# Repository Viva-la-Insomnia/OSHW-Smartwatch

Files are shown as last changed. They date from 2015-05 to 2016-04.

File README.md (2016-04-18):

# OSHW-Smartwatch
This is a repo for EFM32-based smartwatch project.
-- Tuomas Tinus, Jimi Järvelin

Contribute by contacting us / sending in a pull request. 
Welcome additions: integration of https://github.com/NordicSemiconductor/ble-sdk-efm32/, USB code. 
Read the README in the Simplicity_project/ on Simplicity IDE setup details

Our code and hardware are GNU GPL v2 / CERN OHL v1.2, licenses are in the repo. 
However, note that external libraries used in this project are distributed under different licenses, e.g. ARM CMSIS is shared under BSD

Features of the project: 
 - EFM32 low-power microcontroller
 - Lithium battery-powered with charge over USB and battery gauging
 - Bluetooth Low-Energy interface
 - Inertial Measurement Unit (Accelerometer, Gyroscope, Magnetometer)
 - Sharp low-power memory display
 - Separate I2C EEPROM memory (up to 1MB in the current iteration)(switching to flash in the final version)
 - Possible password manager functionality with EFM32 hardware encryption

Current state of project: We have assembled a prototype and are debugging the software. Due to high workload the development has been promptly suspended and will resume in early June 2016

We would like to thank Jared Sanson - http://jared.geek.nz/2014/jul/oshw-oled-watch - for inspiration and design ideas.
Kris Winer - https://github.com/kriswiner/MPU-9250/ - for his MPU-9250 code

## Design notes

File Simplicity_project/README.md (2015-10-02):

How to setup Simplicity IDE for this project
1. Edit Anastasia.slsproj to replace #PATH_TO_PROJECT_DIR with location for your OSHW-Smartwatch repo clone
2. Open Simplicity IDE and press File/Import
3. Select Simplicity Studio/MCU Project
4. Browse the tree to the Anastasia.slsproj
5. If not automatically set, choose Kit as None, EFM32GG332F1024 as the part, EFM32 v4.0.0 SDK, and GNU ARM v4.8.3 toolchain
6. Edit the project directory to (your OSHW-Smartwatch repo clone)/OSHW-Smartwatch/Simplicity_project
Done!

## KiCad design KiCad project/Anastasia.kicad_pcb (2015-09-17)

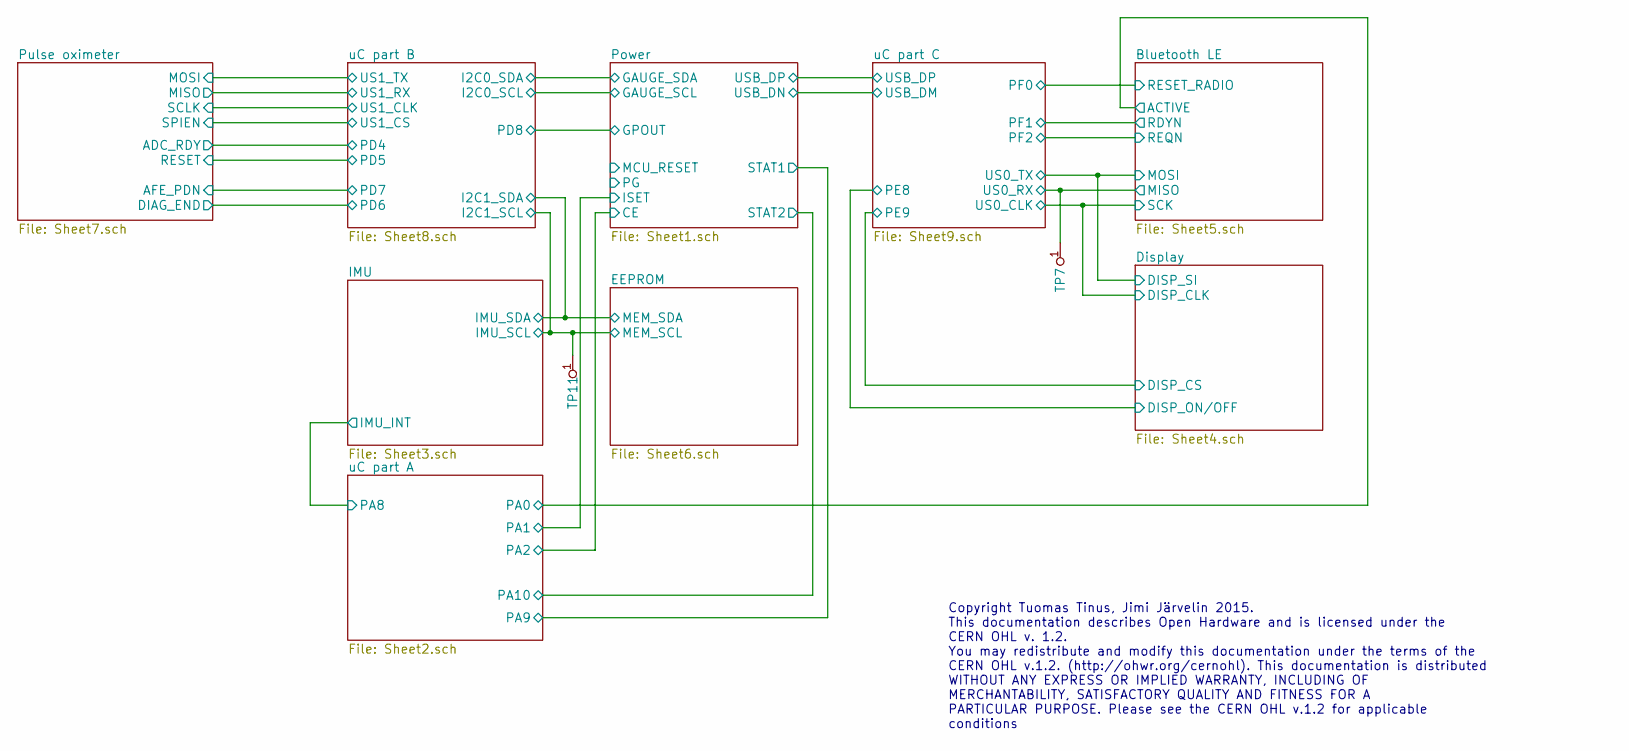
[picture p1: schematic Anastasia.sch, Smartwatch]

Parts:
TP7, TP11: TESTPAD; Test_Point_Round-SMD-Pad

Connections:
/Bluetooth LE/MISO: TP7.1; also elsewhere on the board
/uC part B/I2C1_SCL: TP11.1; also elsewhere on the board

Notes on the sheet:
Copyright Tuomas Tinus, Jimi Järvelin 2015. This documentation describes Open Hardware and is licensed under the CERN OHL v. 1.2. You may redistribute and modify this documentation under the terms of the CERN OHL v.1.2. (http://ohwr.org/cernohl). This documentation is distributed WITHOUT ANY EXPRES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

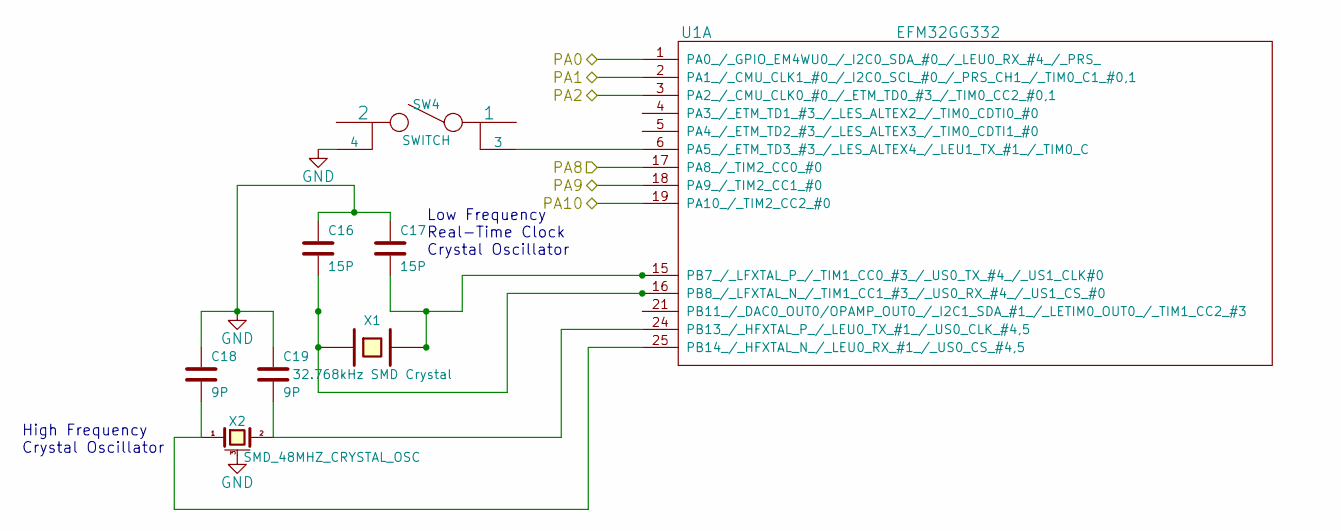
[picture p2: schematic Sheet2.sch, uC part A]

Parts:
C16, C17: 15P; C_0603
C18, C19: 9P; C_0603
SW4: SWITCH; KMS_SMD_SW
U1: EFM32GG332; TQFP-64_10x10mm_Pitch0.5mm
X1: 32.768kHz SMD Crystal; 1.6x1.0CRYSTAL
X2: SMD_48MHZ_CRYSTAL_OSC; 2x1.6

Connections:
/Bluetooth LE/ACTIVE: U1.1 (PA0_/_GPIO_EM4WU0_/_I2C0_SDA_#0_/_LEU0_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); also elsewhere on the board
/IMU/IMU_INT: U1.17 (PA8_/_TIM2_CC0_#0); also elsewhere on the board
/Power/CE: U1.3 (PA2_/_CMU_CLK0_#0_/_ETM_TD0_#3_/_TIM0_C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); also elsewhere on the board
/Power/ISET: U1.2 (PA1_/_CMU_CLK1_#0_/_I2C0_SCL_#0_/_PRS_C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); also elsewhere on the board
/uC part A/PA9: U1.18 (PA9_/_TIM2_CC1_#0); also elsewhere on the board
/uC part A/PA10: U1.19 (PA10_/_TIM2_CC2_#0); also elsewhere on the board
GND: C16.1, C17.1, C18.1, C19.1, SW4.4, X2.3 (case); also elsewhere on the board
unnamed: C16.2, U1.16 (PB8_/_LFXTAL_N_/_TIM1_CC1_#3_/_US0_RX_#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), X1.1
unnamed: C17.2, U1.15 (PB7_/_LFXTAL_P_/_TIM1_CC0_#3_/_US0_TX_#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), X1.2
unnamed: C18.2, U1.25 (PB14_/_HFXTAL_N_/_LEU0_RX_#1_/_US0_CS_#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), X2.1
unnamed: C19.2, U1.24 (PB13_/_HFXTAL_P_/_LEU0_TX_#1_/_US0_CLK_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), X2.2
unnamed: SW4.3, U1.6 (PA5_/_ETM_TD3_#3_/_LES_ALTEX4_/_LEU1_TX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)

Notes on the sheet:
High Frequency Crystal Oscillator
Low Frequency Real-Time Clock Crystal Oscillator

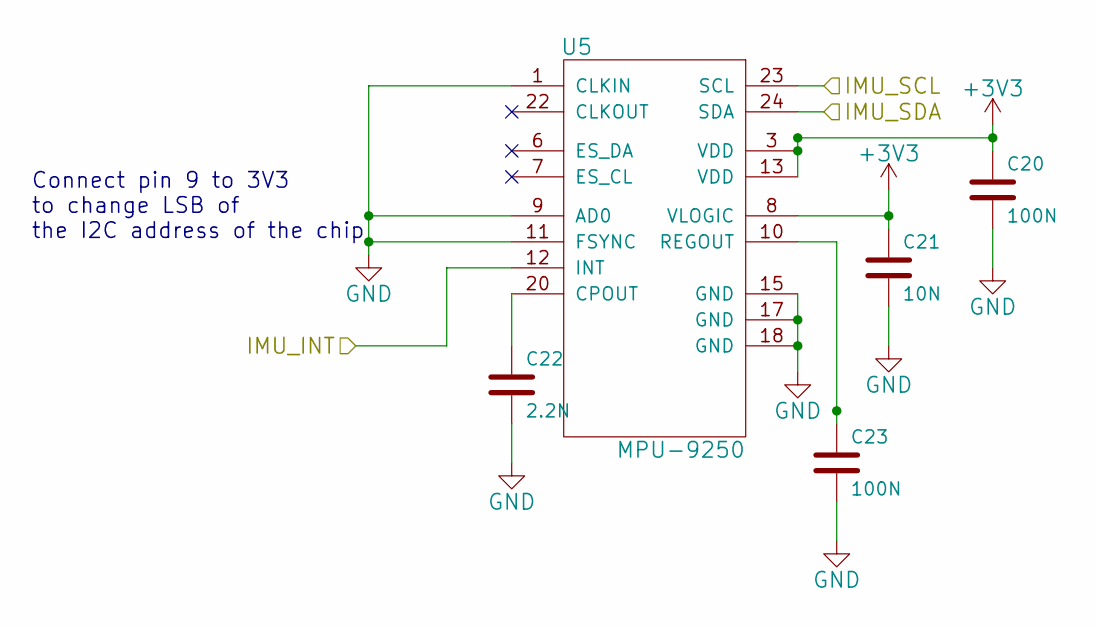
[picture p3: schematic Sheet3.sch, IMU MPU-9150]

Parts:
C20, C23: 100N; C_0603
C21: 10N; C_0603
C22: 2.2N; C_0603
U5: MPU-9250; LGA24

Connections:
+3V3: C20.1, C21.1, U5.3 (VDD), U5.8 (VLOGIC), U5.13 (VDD); also elsewhere on the board
/IMU/IMU_INT: U5.12 (INT); also elsewhere on the board
/uC part B/I2C1_SCL: U5.23 (SCL); also elsewhere on the board
/uC part B/I2C1_SDA: U5.24 (SDA); also elsewhere on the board
GND: C20.2, C21.2, C22.2, C23.2, U5.1 (CLKIN), U5.5 (RESV), U5.9 (AD0), U5.11 (FSYNC), U5.15 (GND), U5.17 (GND), U5.18 (GND); also elsewhere on the board
unnamed: C22.1, U5.20 (CPOUT)
unnamed: C23.1, U5.10 (REGOUT)

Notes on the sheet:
Connect pin 9 to 3V3 to change LSB of the I2C address of the chip

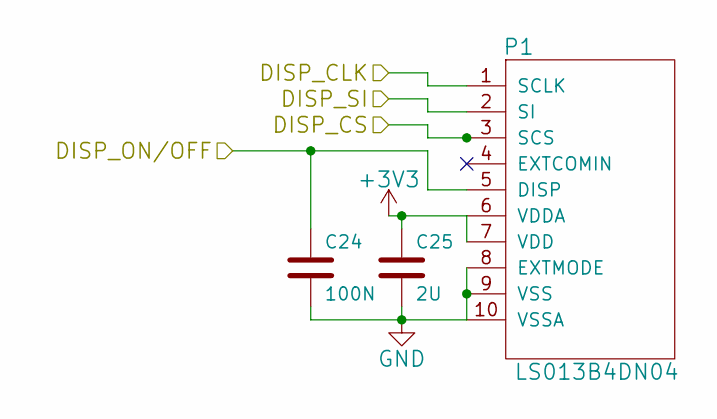
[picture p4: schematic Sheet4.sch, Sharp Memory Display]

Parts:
C24: 100N; C_0603
C25: 2U; C_0603
P1: LS013B4DN04; FPC10

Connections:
+3V3: C25.1, P1.6 (VDDA), P1.7 (VDD); also elsewhere on the board
/Display/DISP_CLK: P1.1 (SCLK); also elsewhere on the board
/Display/DISP_CS: P1.3 (SCS); also elsewhere on the board
/Display/DISP_ON/OFF: C24.1, P1.5 (DISP); also elsewhere on the board
/Display/DISP_SI: P1.2 (SI); also elsewhere on the board
GND: C24.2, C25.2, P1.8 (EXTMODE), P1.9 (VSS), P1.10 (VSSA); also elsewhere on the board

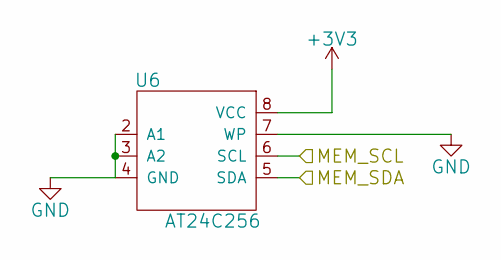
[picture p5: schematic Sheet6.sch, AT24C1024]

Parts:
U6: AT24C256; SOIC-8_3.9x4.9mm_Pitch1.27mm

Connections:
+3V3: U6.8 (VCC); also elsewhere on the board
/uC part B/I2C1_SCL: U6.6 (SCL); also elsewhere on the board
/uC part B/I2C1_SDA: U6.5 (SDA); also elsewhere on the board
GND: U6.2 (A1), U6.3 (A2), U6.4 (GND), U6.7 (WP); also elsewhere on the board

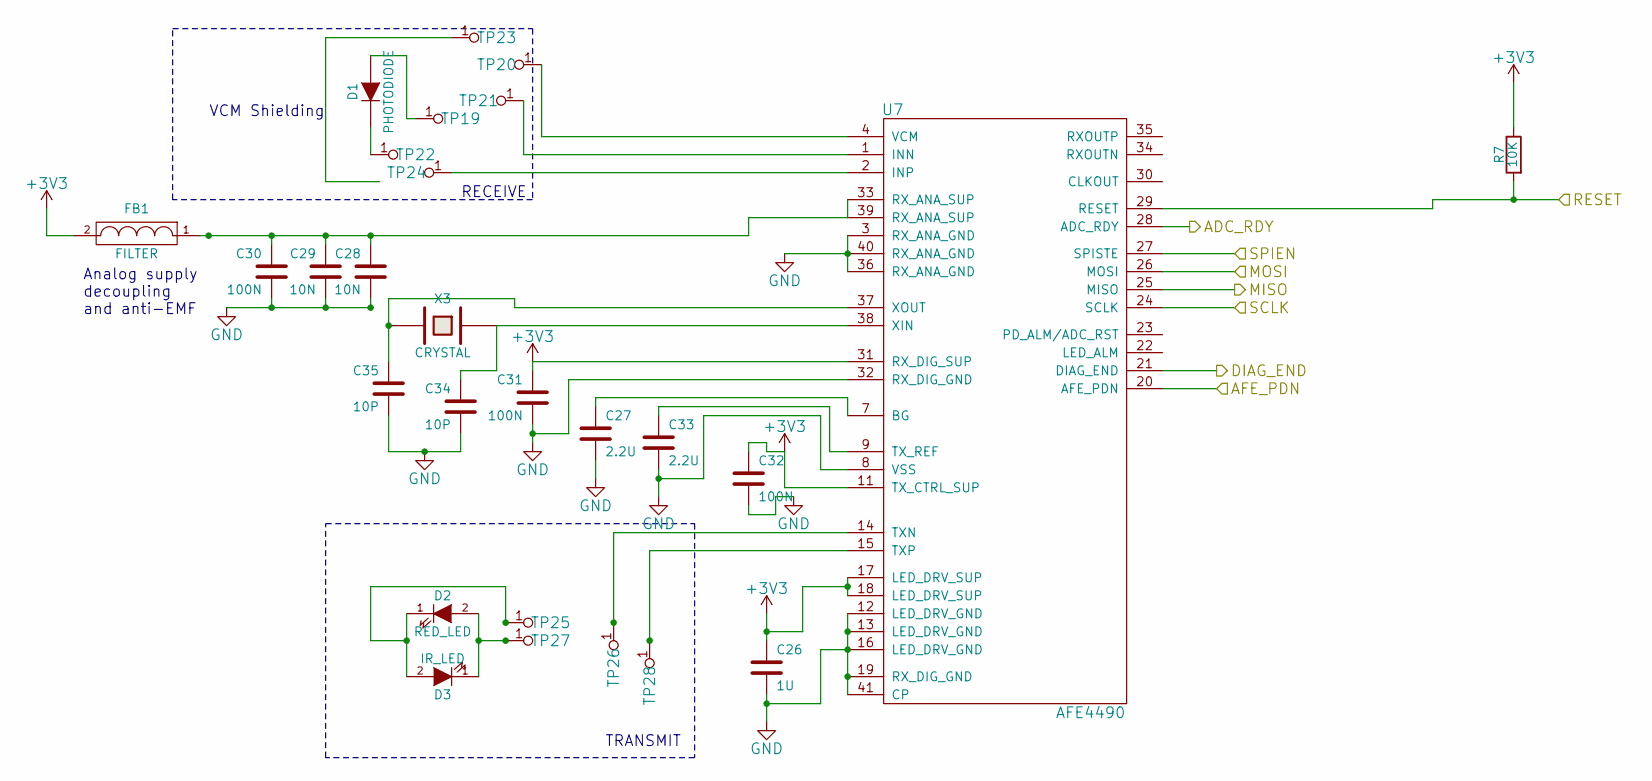
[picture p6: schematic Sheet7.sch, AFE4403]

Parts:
C26: 1U; C_0603
C27, C33: 2.2U; C_0603
C28, C29: 10N; C_0603
C30, C31, C32: 100N; C_0603
C34, C35: 10P; C_0603
D1: PHOTODIODE; BPW34S
D2: RED_LED; R_0603_HandSoldering
D3: IR_LED; 2x1.25mm_LED
FB1: FILTER; C_0603
R7: 10K; R_0603
TP19, TP20, TP21, TP22, TP23, TP24, TP25, TP26, TP27, TP28: TESTPAD; Test_Point_Round-SMD-Pad
U7: AFE4490; QFN40
X3: CRYSTAL; Crystal_Round_Horizontal_3mm

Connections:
+3V3: C26.1, C31.1, C32.1, FB1.2, R7.1, U7.11 (TX_CTRL_SUP), U7.17 (LED_DRV_SUP), U7.18 (LED_DRV_SUP), U7.31 (RX_DIG_SUP); also elsewhere on the board
/Pulse oximeter /ADC_RDY: U7.28 (ADC_RDY); also elsewhere on the board
/Pulse oximeter /AFE_PDN: U7.20 (AFE_PDN); also elsewhere on the board
/Pulse oximeter /DIAG_END: U7.21 (DIAG_END); also elsewhere on the board
/Pulse oximeter /MISO: U7.25 (MISO); also elsewhere on the board
/Pulse oximeter /MOSI: U7.26 (MOSI); also elsewhere on the board
/Pulse oximeter /SCLK: U7.24 (SCLK); also elsewhere on the board
/Pulse oximeter /SPIEN: U7.27 (SPISTE); also elsewhere on the board
/uC part B/PD5: R7.2, U7.29 (RESET); also elsewhere on the board
GND: C26.2, C27.2, C28.2, C29.2, C30.2, C31.2, C32.2, C33.2, C34.2, C35.2, U7.3 (RX_ANA_GND), U7.8 (VSS), U7.12 (LED_DRV_GND), U7.13 (LED_DRV_GND), U7.16 (LED_DRV_GND), U7.19 (RX_DIG_GND), U7.32 (RX_DIG_GND), U7.36 (RX_ANA_GND), U7.40 (RX_ANA_GND), U7.41 (CP); also elsewhere on the board
unnamed: C27.1, U7.7 (BG)
unnamed: C28.1, C29.1, C30.1, FB1.1, U7.33 (RX_ANA_SUP), U7.39 (RX_ANA_SUP)
unnamed: C33.1, U7.9 (TX_REF)
unnamed: C34.1, U7.38 (XIN), X3.1
unnamed: C35.1, U7.37 (XOUT), X3.2
unnamed: D1.1 (A), TP19.1
unnamed: D1.2 (K), TP22.1
unnamed: D2.1 (K), D3.2 (A), TP25.1
unnamed: D2.2 (A), D3.1 (K), TP27.1
unnamed: TP20.1, U7.4 (VCM)
unnamed: TP21.1, U7.1 (INN)
unnamed: TP24.1, U7.2 (INP)
unnamed: TP26.1, U7.14 (TXN)
unnamed: TP28.1, U7.15 (TXP)

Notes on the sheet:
TRANSMIT
RECEIVE
VCM Shielding
Analog supply decoupling and anti-EMF

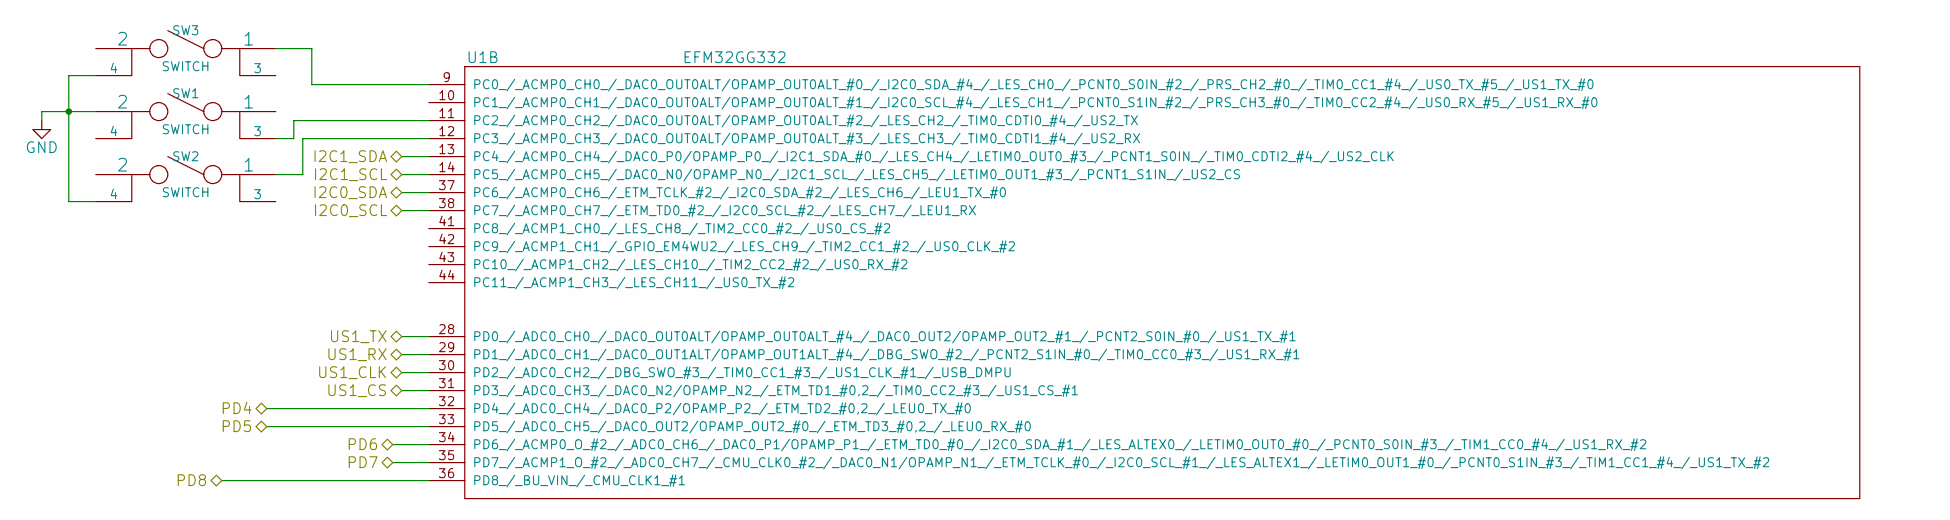
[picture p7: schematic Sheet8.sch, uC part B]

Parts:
SW1, SW2, SW3: SWITCH; KMS_SMD_SW
U1: EFM32GG332; TQFP-64_10x10mm_Pitch0.5mm

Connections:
/Power/GAUGE_SCL: U1.38 (PC7_/_ACMP0_CH7_/_ETM_TD0_#2_/_I2C0_SCL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); also elsewhere on the board
/Power/GAUGE_SDA: U1.37 (PC6_/_ACMP0_CH6_/_ETM_TCLK_#2_/_I2C0_SD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); also elsewhere on the board
/Power/GPOUT: U1.36 (PD8_/_BU_VIN_/_CMU_CLK1_#1); also elsewhere on the board
/Pulse oximeter /ADC_RDY: U1.32 (PD4_/_ADC0_CH4_/_DAC0_P2/OPAMP_P2_/_ETM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); also elsewhere on the board
/Pulse oximeter /AFE_PDN: U1.35 (PD7_/_ACMP1_O_#2_/_ADC0_CH7_/_CMU_CLK0_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); also elsewhere on the board
/Pulse oximeter /DIAG_END: U1.34 (PD6_/_ACMP0_O_#2_/_ADC0_CH6_/_DAC0_P1/O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); also elsewhere on the board
/Pulse oximeter /MISO: U1.29 (PD1_/_ADC0_CH1_/_DAC0_OUT1ALT/OPAMP_OUT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); also elsewhere on the board
/Pulse oximeter /MOSI: U1.28 (PD0_/_ADC0_CH0_/_DAC0_OUT0ALT/OPAMP_OUT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); also elsewhere on the board
/Pulse oximeter /SCLK: U1.30 (PD2_/_ADC0_CH2_/_DBG_SWO_#3_/_TIM0_CC1_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); also elsewhere on the board
/Pulse oximeter /SPIEN: U1.31 (PD3_/_ADC0_CH3_/_DAC0_N2/OPAMP_N2_/_ETM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); also elsewhere on the board
/uC part B/I2C1_SCL: U1.14 (PC5_/_ACMP0_CH5_/_DAC0_N0/OPAMP_N0_/_I2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); also elsewhere on the board
/uC part B/I2C1_SDA: U1.13 (PC4_/_ACMP0_CH4_/_DAC0_P0/OPAMP_P0_/_I2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); also elsewhere on the board
/uC part B/PD5: U1.33 (PD5_/_ADC0_CH5_/_DAC0_OUT2/OPAMP_OUT2_#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); also elsewhere on the board
GND: SW1.2, SW2.4, SW3.4; also elsewhere on the board
unnamed: SW1.3, U1.11 (PC2_/_ACMP0_CH2_/_DAC0_OUT0ALT/OPAMP_OU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)
unnamed: SW2.1, U1.12 (PC3_/_ACMP0_CH3_/_DAC0_OUT0ALT/OPAMP_OU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)
unnamed: SW3.1, U1.9 (PC0_/_ACMP0_CH0_/_DAC0_OUT0ALT/OPAMP_OU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)

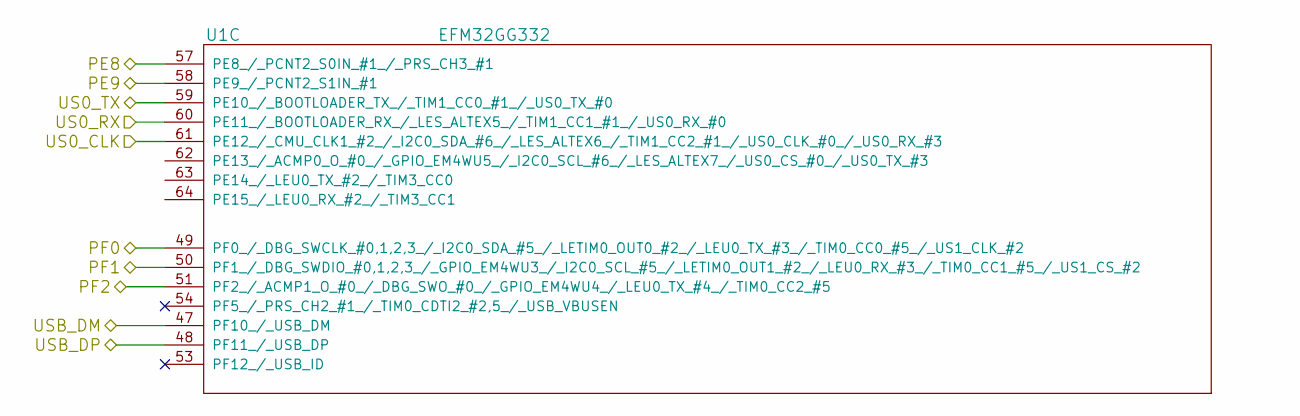
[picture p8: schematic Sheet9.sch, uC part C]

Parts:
U1: EFM32GG332; TQFP-64_10x10mm_Pitch0.5mm

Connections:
/Bluetooth LE/MISO: U1.60 (PE11_/_BOOTLOADER_RX_/_LES_ALTEX5_/_TIM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); also elsewhere on the board
/Display/DISP_CLK: U1.61 (PE12_/_CMU_CLK1_#2_/_I2C0_SDA_#6_/_LES_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); also elsewhere on the board
/Display/DISP_CS: U1.58 (PE9_/_PCNT2_S1IN_#1); also elsewhere on the board
/Display/DISP_ON/OFF: U1.57 (PE8_/_PCNT2_S0IN_#1_/_PRS_CH3_#1); also elsewhere on the board
/Display/DISP_SI: U1.59 (PE10_/_BOOTLOADER_TX_/_TIM1_CC0_#1_/_US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); also elsewhere on the board
/Power/USB_DP: U1.48 (PF11_/_USB_DP); also elsewhere on the board
/uC part C/PF0: U1.49 (PF0_/_DBG_SWCLK_#0,1,2,3_/_I2C0_SDA_#5_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); also elsewhere on the board
/uC part C/PF1: U1.50 (PF1_/_DBG_SWDIO_#0,1,2,3_/_GPIO_EM4WU3_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); also elsewhere on the board
/uC part C/PF2: U1.51 (PF2_/_ACMP1_O_#0_/_DBG_SWO_#0_/_GPIO_EM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); also elsewhere on the board
/uC part C/USB_DM: U1.47 (PF10_/_USB_DM); also elsewhere on the board

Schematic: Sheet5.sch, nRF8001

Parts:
C36: 4.7U; C_0603
C37, C41: 100N; C_0603
C38: 1N; C_0603
C39, C40: 10P; C_0603
C42: 1U; C_0603
C43: 33N; C_0603
C44: 1.8N; C_0603
C45: 1.2N; C_0603
C46: 2.2N; C_0603
C47: N/C; R_0603_HandSoldering
L2: 15NH; R_0603
L3: 10UH; R_0603
L4: 5.6NH; R_0603
L5: 8.2NH; R_0603
L6: 3.9NH; R_0603
R8: 22K; R_0603
TP17, TP18: TESTPAD; Test_Point_Round-SMD-Pad
U8: nRF8001; QFN32
X4: CRYSTAL_SMD_16MHZ; 2x1.6CRYSTAL

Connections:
+3V3: C36.1, C37.1, C38.1, C42.1, L2.2, U8.1 (VDD), U8.9 (VDD), U8.24 (AVDD), U8.26 (AVDD), U8.29 (AVDD); also elsewhere on the board
/Bluetooth LE/ACTIVE: U8.6 (ACTIVE); also elsewhere on the board
/Bluetooth LE/MISO: U8.14 (MISO); also elsewhere on the board
/Display/DISP_CLK: U8.11 (SCK); also elsewhere on the board
/Display/DISP_SI: U8.13 (MOSI); also elsewhere on the board
/uC part C/PF0: U8.19 (RESET); also elsewhere on the board
/uC part C/PF1: U8.16 (RDYN); also elsewhere on the board
/uC part C/PF2: U8.12 (REQN); also elsewhere on the board
GND: C36.2, C37.2, C38.2, C39.2, C40.2, C41.2, C42.2, C43.2, C45.2, C46.2, C47.2, R8.1, U8.8 (VSS), U8.17 (VSS), U8.18 (VSS), U8.23 (VSS), U8.30 (VSS), U8.31 (VSS), U8.33 (VSS), X4.3 (case); also elsewhere on the board
unnamed: C39.1, U8.27 (XC2), X4.1
unnamed: C40.1, U8.28 (XC1), X4.2
unnamed: C41.1, U8.2 (DBC1)
unnamed: C43.1, U8.3 (DBC2)
unnamed: C44.1, L6.1
unnamed: C44.2, C45.1
unnamed: C46.1, C47.1, L4.1, U8.20 (VDD_PA)
unnamed: L2.1, L3.2
unnamed: L3.1, U8.32 (DCC)
unnamed: L4.2, L5.1, U8.21 (ANT1)
unnamed: L5.2, L6.2, U8.22 (ANT2)
unnamed: R8.2, U8.25 (IREF)
unnamed: TP17.1, U8.7 (TXD)
unnamed: TP18.1, U8.10 (RXD)

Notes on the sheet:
DIFFERENTIAL ANTENNA PAY ATTENTION TO PCB ROUTING (EMF!!!)
For the internal DC-DC Lowers power consumption Can be avoided in the final design

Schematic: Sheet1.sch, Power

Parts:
BT1: BATTERY
C1, C8, C9, C10, C13: 100N; C_0603
C2, C4: 1U; C_0603
C3, C14: 4.7U; C_0603
C5, C11: 10U; C_0603
C6, C7: 10N; C_0603
C12: 2.2U; C_0603
C15: 0.47U; C_0603
CON1: USB-MICRO-B; USB_Micro-B
L1: 47UH; R_0603
R1: 1R; R_0603
R2: 1K; R_0603
R3: 4K7; R_0603
R4, R6: 15R; R_0603
R5: 1.8M; R_0603
U1: EFM32GG332; TQFP-64_10x10mm_Pitch0.5mm
U2: BQ25011; VQFN20
U3: BQ27421-G1; DSBGA9
U4: IP4220CZ6; SOT457

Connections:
+3V3: C8.1, C9.1, C10.1, C11.1, C12.1, L1.1, R1.2, R2.1, U1.7 (IOVDD_0), U1.26 (IOVDD_3), U1.39 (VDD_DREG), U1.55 (IOVDD_5), U2.2 (FB); also elsewhere on the board
/Power/CE: U2.15 (CE); also elsewhere on the board
/Power/GAUGE_SCL: U3.A3 (SCL); also elsewhere on the board
/Power/GAUGE_SDA: U3.A2 (SDA); also elsewhere on the board
/Power/GPOUT: U3.A1 (GPOUT); also elsewhere on the board
/Power/ISET: U2.13 (ISET2); also elsewhere on the board
/Power/MCU_RESET: C1.1, U1.20 (RESETn)
/Power/PG: U2.14 (PG)
/Power/USB_DP: R4.1; also elsewhere on the board
/uC part A/PA9: U2.7 (STAT1); also elsewhere on the board
/uC part A/PA10: U2.8 (STAT2); also elsewhere on the board
/uC part C/USB_DM: R6.1; also elsewhere on the board
GND: BT1.2 (-), C1.2, C2.2, C3.2, C4.2, C5.2, C6.2, C7.2, C8.2, C9.2, C10.2, C11.2, C12.2, C13.2, C14.2, C15.2, CON1.5 (GND), CON1.6 (SHELL1), CON1.7 (SHELL2), CON1.8 (SHELL3), CON1.9 (SHELL4), R3.1, R5.2, U1.8 (VSS), U1.22 (VSS), U1.56 (VSS), U2.3 (VSS), U2.9 (VSS), U2.18 (VSS), U3.B2 (VSS), U3.C1 (VSS), U4.2 (GND); also elsewhere on the board
unnamed: BT1.1 (+), C14.1, U3.C3 (BAT)
unnamed: C2.1, U1.40 (DECOUPLE)
unnamed: C4.1, U1.46 (USB_VREGO)
unnamed: C5.1, C6.1, C7.1, R1.1, U1.23 (AVDD_1), U1.27 (AVDD_0)
unnamed: C15.1, U3.B3 (VDD)
unnamed: CON1.2 (D-), R6.2, U4.4 (I/O_3)
unnamed: CON1.3 (D+), R4.2, U4.6 (I/O_4)
unnamed: L1.2, U2.19 (SW)
unnamed: R2.2, U2.4 (EN)
unnamed: R3.2, U2.12 (ISET1)
unnamed: R5.1, U3.B1 (BIN)
unnamed: U2.16 (BAT/OUT), U2.17 (BAT/OUT), U3.C2 (SRX)
USB_VBUS: C3.1, C13.1, CON1.1 (VBUS), U1.45 (USB_VREGI), U1.52 (USB_VBUS), U2.6 (USB), U4.5 (VIN)

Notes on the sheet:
Power capacitors
The uC reset line
USB connector and data lines
USB Power to IC
ESD Protection
Battery Charge Current Set Resistor
Battery Gauge

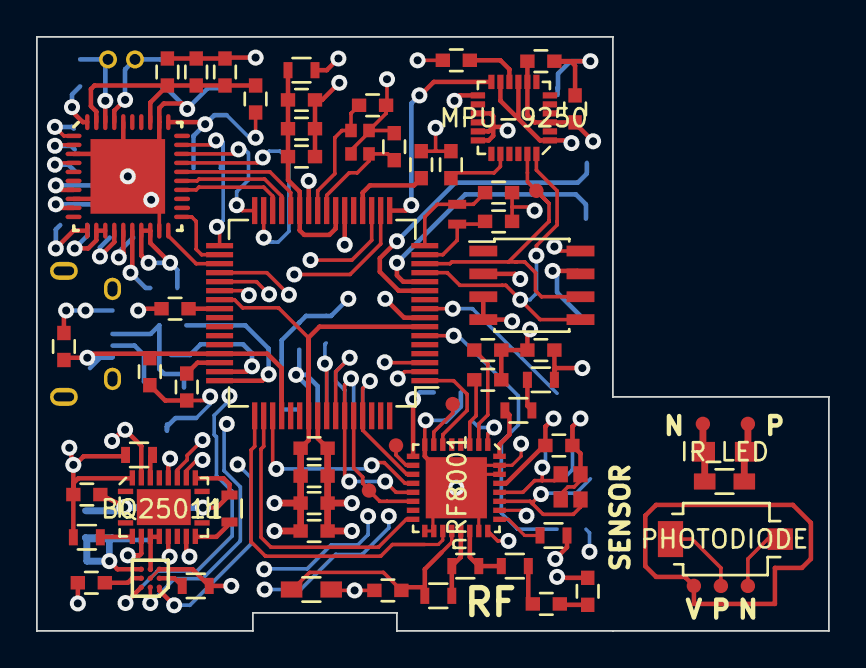
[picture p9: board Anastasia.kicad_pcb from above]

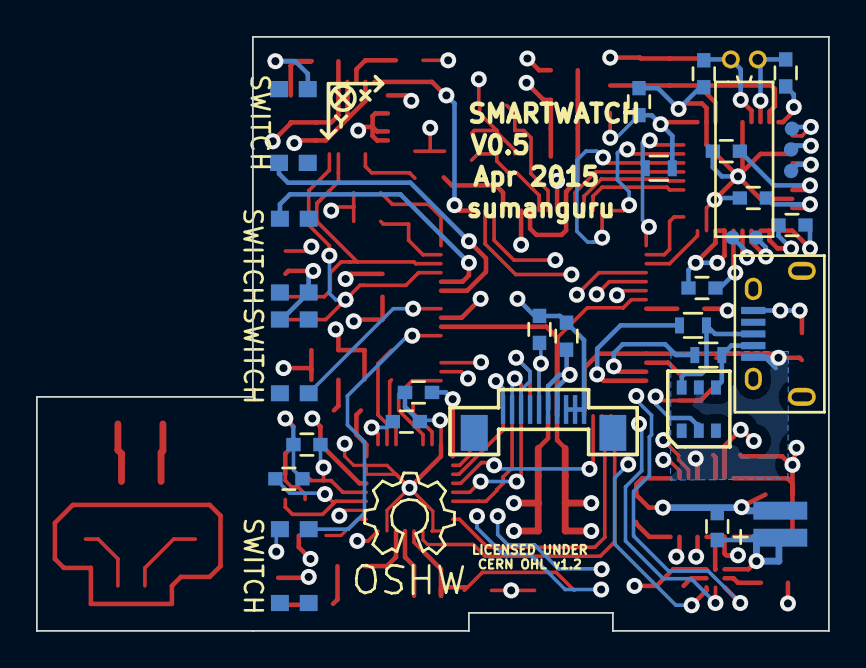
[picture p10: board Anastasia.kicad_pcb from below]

Board: 4 copper layers, 44.0 x 33.0 mm, 98 parts (31 on the bottom side), 83 nets.

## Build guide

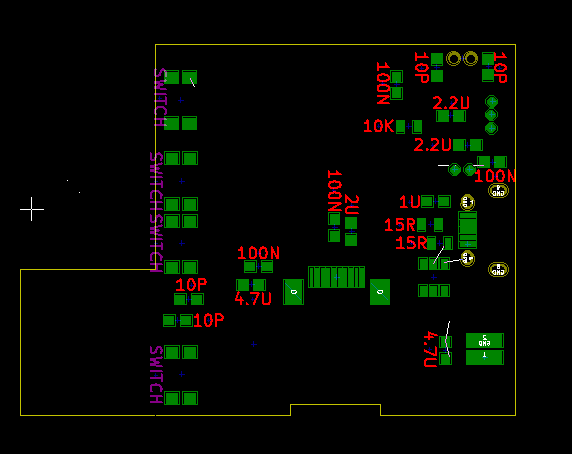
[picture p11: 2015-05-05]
v0.5 files/Bottom assembly.png

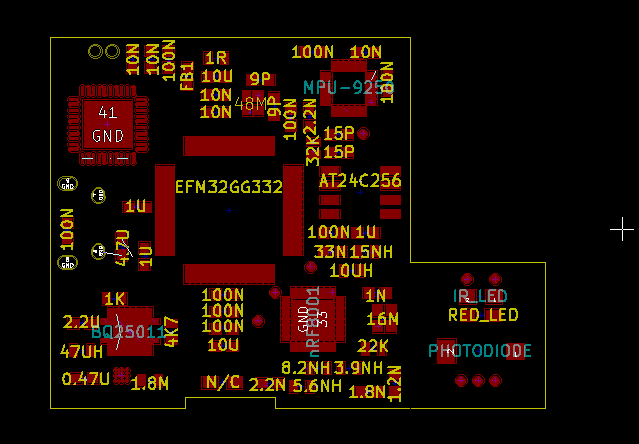
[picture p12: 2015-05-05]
v0.5 files/Top assembly.png

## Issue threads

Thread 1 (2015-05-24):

PCB layout

sumanguru, 2015-05-24:
Some components are not properly isolated - on v0.5 PCB with untinted vias USB port would short out vias underneath it and the analog frontend crystal could short the traces underneath - both have conductive casing

sumanguru, 2016-01-05:
Current versions of KiCad cannot selectively tent vias. Currently we want untented vias, since they serve as test points. The issue will need to be resolved with post-generation edit of production Gerbers to tent the vias.

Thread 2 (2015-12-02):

PCB layout issues

sumanguru, 2015-12-02:
The footprint for BQ25010 is incorrect and there is no button on the bootloader pin

sumanguru, 2015-12-19:
The bootloader pin is tied to BLE reset pin, which has internal pullup -> chip goes to bootloader at boot automatically

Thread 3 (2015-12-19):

Rendering

sumanguru, 2015-12-19:
When in the current demo code 10-80 is changed to 30-50 code stops working for unknown reason (hidden bug?)

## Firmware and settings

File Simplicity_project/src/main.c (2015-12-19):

/**************************************************************************//**
 * @file
 * @brief Empty Project
 * @author Energy Micro AS
 * @version 3.20.2
 ******************************************************************************
 * @section License
 * <b>(C) Copyright 2014 Silicon Labs, http://www.silabs.com</b>
 *******************************************************************************
 *
 * This file is licensed under the Silicon Labs Software License Agreement. See 
 * "http://developer.silabs.com/legal/version/v11/Silicon_Labs_Software_License_Agreement.txt"  
 * for details. Before using this software for any purpose, you must agree to the 
 * terms of that agreement.
 *
 ******************************************************************************/
/**************************************************************************//**
 * @file main.c
 * @brief OSHW-Smartwatch main code
 * @author Tuomas Tinus, Jimi Järvelin
 * @version 0.5
 ******************************************************************************/

#include "em_device.h"
#include "em_chip.h"
#include "udelay.h"
#include "mdelay.h"
#include "BQ25010.h"
#include "BQ27421.h"
#include "MPU9250.h"
#include "LS013_MD.h"
#include "InitDevice.h"
#include "Graphics.h"
#include "rtc.h"
#include "EEPROM.h"
#include "em_usart.h"
#include "em_gpio.h"

int main(void)
{
	/* Initialise the chip - included for backwards compatibility.
	 * Do not add code before this point							*/
	CHIP_Init();

	/* Start in default mode */
	enter_DefaultMode_from_RESET();

	//Calibrate the delay function
	UDELAY_Calibrate();

	/* Initialise the subsystems
	 * after 150ms delay for them to boot */
	//UDELAY_Delay(150);

	LS013_Init();
	LS013_Enable();
	UDELAY_Delay(250);
	//LS013_SetBuffer(LoadingBackground);

	uint16_t cook[4];
	cook[0] = 0xa55a;
	cook[1] = 0x5aa5;
	cook[2] = 0xa55a;
	cook[3] = 0x5aa5;
	Sprite sprite;
	sprite.HEIGHT = 8;
	sprite.WIDTH = 8;
	sprite.SPRITE = cook;

	while(1){
		for (uint32_t i = 10; i<80; i++ ){
			LS013_DrawSprite( i, 10, sprite );
			LS013_Refresh(0);
			LS013_ClearBufferArea( i, 10, sprite.WIDTH, sprite.HEIGHT, 0 );
		}
		for (uint32_t i = 10; i<80; i++ ){
			LS013_DrawSprite( 80, i, sprite );
			LS013_Refresh(0);
			LS013_ClearBufferArea( 80, i, sprite.WIDTH, sprite.HEIGHT, 0 );
		}
		for (uint32_t i = 80; i>10; i-- ){
			LS013_DrawSprite( i, 80, sprite );
			LS013_Refresh(0);
			LS013_ClearBufferArea( i, 80, sprite.WIDTH, sprite.HEIGHT, 0 );
		}
		for (uint32_t i = 80; i>10; i-- ){
			LS013_DrawSprite( 10, i, sprite );
			LS013_Refresh(0);
			LS013_ClearBufferArea( 10, i, sprite.WIDTH, sprite.HEIGHT, 0 );
		}
	}
	//RTC_Mod_Init();
	//BQ25010_init();
	//BQ27421_Init();
	//MPU9250_Init();

	/* Uncomment when we solder in the MPU
	float AK8963_sensitivityadj[3];
	MPU9250_InitAK8963(AK8963_sensitivityadj);

	float gyro_bias[3];
	float	acc_bias[3];
	MPU9250_Calibrate(gyro_bias, acc_bias);

	float selftest_results[6];
	MPU9250_SelfTest(selftest_results);
	*/

  // Infinite loop
	while (1) {
		UDELAY_Delay(200);
		//LS013_InvertPolarity();
	}
}

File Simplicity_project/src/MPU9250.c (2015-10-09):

/**************************************************************************//**
 * @file MPU9250.c
 * @brief MPU9250 interface code
 * @author Tuomas Tinus, Jimi Järvelin
 * @version 0.5
 * @note Builds upon Kris Winer's https://github.com/kriswiner/MPU-9250/
 * 		 and basically is a port with some changes
 ******************************************************************************/

/* NOTE Implement different error codes
 * and system log. Replace i2cTransferDone
 * poll with more functional version
 * for the purpose of error detection	    */

/*INCLUDES*/
#include "MPU9250.h"
#include "em_system.h"
#include "em_device.h"
#include "em_chip.h"
#include "em_gpio.h"
#include "em_i2c.h"
#include "math.h"

/*DEFINES*/
#define MPU9250_ADDR 	0xD0
#define AK8963_ADDR_MPU 0x0C //MPU9250 and EFM32 emlib specs have different formats for I2C address
#define AK8963_ADDR_EFM 0x18 //Would need the MPU address if you set AK8963 as MPU-9250 slave

// See also MPU-9250 Register Map and Descriptions, Revision 4.0, RM-MPU-9250A-00, Rev. 1.4, 9/9/2013 for registers not listed in
// above document; the MPU9250 and MPU9150 are virtually identical but the latter has a different register map
//
//MPU-9250 Registers
#define SELF_TEST_X_GYRO 0x00
#define SELF_TEST_Y_GYRO 0x01
#define SELF_TEST_Z_GYRO 0x02

//Register values left from MPU-9150. Are not defined in MPU-9250 Reference
/*#define X_FINE_GAIN      0x03 // [7:0] fine gain
#define Y_FINE_GAIN      0x04
#define Z_FINE_GAIN      0x05
#define XA_OFFSET_H      0x06 // User-defined trim values for accelerometer
#define XA_OFFSET_L_TC   0x07
#define YA_OFFSET_H      0x08
#define YA_OFFSET_L_TC   0x09
#define ZA_OFFSET_H      0x0A
#define ZA_OFFSET_L_TC   0x0B */

#define SELF_TEST_X_ACCEL 0x0D
#define SELF_TEST_Y_ACCEL 0x0E
#define SELF_TEST_Z_ACCEL 0x0F

#define SELF_TEST_A      0x10

#define XG_OFFSET_H      0x13  // User-defined trim values for gyroscope
#define XG_OFFSET_L      0x14
#define YG_OFFSET_H      0x15
#define YG_OFFSET_L      0x16
#define ZG_OFFSET_H      0x17
#define ZG_OFFSET_L      0x18
#define SMPLRT_DIV       0x19
#define CONFIG           0x1A
#define GYRO_CONFIG      0x1B
#define ACCEL_CONFIG     0x1C
#define ACCEL_CONFIG2    0x1D
#define LP_ACCEL_ODR     0x1E
#define WOM_THR          0x1F

#define MOT_DUR          0x20  // Duration counter threshold for motion interrupt generation, 1 kHz rate, LSB = 1 ms
#define ZMOT_THR         0x21  // Zero-motion detection threshold bits [7:0]
#define ZRMOT_DUR        0x22  // Duration counter threshold for zero motion interrupt generation, 16 Hz rate, LSB = 64 ms

#define FIFO_EN          0x23
#define I2C_MST_CTRL     0x24
#define I2C_SLV0_ADDR    0x25
#define I2C_SLV0_REG     0x26
#define I2C_SLV0_CTRL    0x27
#define I2C_SLV1_ADDR    0x28
#define I2C_SLV1_REG     0x29
#define I2C_SLV1_CTRL    0x2A
#define I2C_SLV2_ADDR    0x2B
#define I2C_SLV2_REG     0x2C
#define I2C_SLV2_CTRL    0x2D
#define I2C_SLV3_ADDR    0x2E
#define I2C_SLV3_REG     0x2F
#define I2C_SLV3_CTRL    0x30
#define I2C_SLV4_ADDR    0x31
#define I2C_SLV4_REG     0x32
#define I2C_SLV4_DO      0x33
#define I2C_SLV4_CTRL    0x34
#define I2C_SLV4_DI      0x35
#define I2C_MST_STATUS   0x36
#define INT_PIN_CFG      0x37
#define INT_ENABLE       0x38
#define DMP_INT_STATUS   0x39  // Check DMP interrupt
#define INT_STATUS       0x3A
#define ACCEL_XOUT_H     0x3B
#define ACCEL_XOUT_L     0x3C
#define ACCEL_YOUT_H     0x3D
#define ACCEL_YOUT_L     0x3E
#define ACCEL_ZOUT_H     0x3F
#define ACCEL_ZOUT_L     0x40
#define TEMP_OUT_H       0x41
#define TEMP_OUT_L       0x42
#define GYRO_XOUT_H      0x43
#define GYRO_XOUT_L      0x44
#define GYRO_YOUT_H      0x45
#define GYRO_YOUT_L      0x46
#define GYRO_ZOUT_H      0x47
#define GYRO_ZOUT_L      0x48
#define EXT_SENS_DATA_00 0x49
#define EXT_SENS_DATA_01 0x4A
#define EXT_SENS_DATA_02 0x4B
#define EXT_SENS_DATA_03 0x4C
#define EXT_SENS_DATA_04 0x4D
#define EXT_SENS_DATA_05 0x4E
#define EXT_SENS_DATA_06 0x4F
#define EXT_SENS_DATA_07 0x50
#define EXT_SENS_DATA_08 0x51
#define EXT_SENS_DATA_09 0x52
#define EXT_SENS_DATA_10 0x53
#define EXT_SENS_DATA_11 0x54
#define EXT_SENS_DATA_12 0x55
#define EXT_SENS_DATA_13 0x56
#define EXT_SENS_DATA_14 0x57
#define EXT_SENS_DATA_15 0x58
#define EXT_SENS_DATA_16 0x59
#define EXT_SENS_DATA_17 0x5A
#define EXT_SENS_DATA_18 0x5B
#define EXT_SENS_DATA_19 0x5C
#define EXT_SENS_DATA_20 0x5D
#define EXT_SENS_DATA_21 0x5E
#define EXT_SENS_DATA_22 0x5F
#define EXT_SENS_DATA_23 0x60
#define MOT_DETECT_STATUS 0x61
#define I2C_SLV0_DO      0x63
#define I2C_SLV1_DO      0x64
#define I2C_SLV2_DO      0x65
#define I2C_SLV3_DO      0x66
#define I2C_MST_DELAY_CTRL 0x67
#define SIGNAL_PATH_RESET  0x68
#define MOT_DETECT_CTRL  0x69
#define USER_CTRL        0x6A  // Bit 7 enable DMP, bit 3 reset DMP
#define PWR_MGMT_1       0x6B // Device defaults to the SLEEP mode
#define PWR_MGMT_2       0x6C
#define DMP_BANK         0x6D  // Activates a specific bank in the DMP
#define DMP_RW_PNT       0x6E  // Set read/write pointer to a specific start address in specified DMP bank
#define DMP_REG          0x6F  // Register in DMP from which to read or to which to write
#define DMP_REG_1        0x70
#define DMP_REG_2        0x71
#define FIFO_COUNTH      0x72
#define FIFO_COUNTL      0x73
#define FIFO_R_W         0x74
#define MPU9250_WHO_AM_I 0x75 // Should return 0x71
#define XA_OFFSET_H      0x77
#define XA_OFFSET_L      0x78
#define YA_OFFSET_H      0x7A
#define YA_OFFSET_L      0x7B
#define ZA_OFFSET_H      0x7D
#define ZA_OFFSET_L      0x7E

//Magnetometer Registers
#define AK8963_WHO_AM_I  0x00 // should return 0x48
#define AK8963_INFO      0x01
#define AK8963_ST1       0x02  // data ready status bit 0
#define AK8963_XOUT_L	 0x03  // data
#define AK8963_XOUT_H	 0x04
#define AK8963_YOUT_L	 0x05
#define AK8963_YOUT_H	 0x06
#define AK8963_ZOUT_L	 0x07
#define AK8963_ZOUT_H	 0x08
#define AK8963_ST2       0x09  // Data overflow bit 3 and data read error status bit 2
#define AK8963_CNTL      0x0A  // Power down (0000), single-measurement (0001), self-test (1000) and Fuse ROM (1111) modes on bits 3:0
#define AK8963_ASTC      0x0C  // Self test control
#define AK8963_I2CDIS    0x0F  // I2C disable
#define AK8963_ASAX      0x10  // Fuse ROM x-axis sensitivity adjustment value
#define AK8963_ASAY      0x11  // Fuse ROM y-axis sensitivity adjustment value
#define AK8963_ASAZ      0x12  // Fuse ROM z-axis sensitivity adjustment value

// Sensor sensitivity scales
enum Ascale {
  AFS_2G = 0,
  AFS_4G,
  AFS_8G,
  AFS_16G
};

enum Gscale {
  GFS_250DPS = 0,
  GFS_500DPS,
  GFS_1000DPS,
  GFS_2000DPS
};

enum Mscale {
  MFS_14BITS = 0, // 0.6 mG per LSB
  MFS_16BITS      // 0.15 mG per LSB
};
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

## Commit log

2015-03-14 Create BOM&Features
2015-03-14 KiCad project file import
    Schematics & libraries for the project
    [Anastasia.sch]
2015-03-14 Power and USB schematics
2015-03-14 Power and USB schematics
    The actual schematics file updates
    [Anastasia.sch]
2015-03-15 IMU and crystal schematics
    Added schematics for crystal oscillators of the main uC and schematic
    for MPU-9150 and passive components. Miscellaneous updates and
    annotations
    [Anastasia.sch, Sheet1.sch, Sheet2.sch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]
2015-03-16 Bluetooth schematics
    nRF8001 schematics, various additions and modification, test points
    added
    [Anastasia.sch, Sheet1.sch, Sheet2.sch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]
2015-03-16 BOM additions
2015-03-17 Create Power Consumption (no LEDs)
2015-03-18 Update Power Consumption
2015-03-21 EEPROM schematics
    [Anastasia.sch, Sheet1.sch, Sheet2.sch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]
2015-03-21 IC packages, bugfixes
    drawings for IC packages, associations, schematic fixes
    [$Anastasia.sch, Anastasia.kicad_pcb, Anastasia.sch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]
2015-03-21 New packages, PCB
    [$Anastasia.sch, $Sheet7.sch, Anastasia.sch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]
2015-03-23 Schematics, PCB design
    New schematics for the pulse oximeter, PCB layout design
    [$Sheet7.sch, Anastasia.kicad_pcb, Anastasia.sch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]
2015-03-26 PCB design
    Routing for the main components, except for the power section
    [Anastasia.kicad_pcb, Anastasia.sch, Sheet1.sch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]
2015-04-07 PCB finalised, Gerbers created for v0.5
    New footprints, fixes in schematic, PCB final design, plotted Gerbers
    for prototype production
    [Anastasia-B_Cu.gbr, Anastasia-B_Mask.gbr, Anastasia-B_SilkS.gbr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]
2015-05-05 Refactoring and assembly assist files
    [Anastasia-B_Cu.gbr, Anastasia-B_Mask.gbr, Anastasia-B_SilkS.gbr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]
2015-05-28 Modifications for compliance with CERN OHL
    [Anastasia.kicad_pcb, Anastasia.sch]
2015-05-30 Software setup
    [Anastasia.sch]
2015-06-23 Small bugfixes and AFE4490 lib template
    [MPU9250.c, main.c]
2015-09-17 Solder stencil files and misc. corrections
    [Anastasia.kicad_pcb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]
2015-10-02 Refactoring, mods for easier accessibility, cleanup, port to IDE v3.1
    [Anastasia-B_Cu.gbr, Anastasia-B_Mask.gbr, Anastasia-B_Paste.gbr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]
2015-12-02 Major alterations to display drivers and refactoring
2015-12-17 Preliminary changes to display drivers
2015-12-19 Fixes to display drivers
    [LS013_MD.c, main.c]
